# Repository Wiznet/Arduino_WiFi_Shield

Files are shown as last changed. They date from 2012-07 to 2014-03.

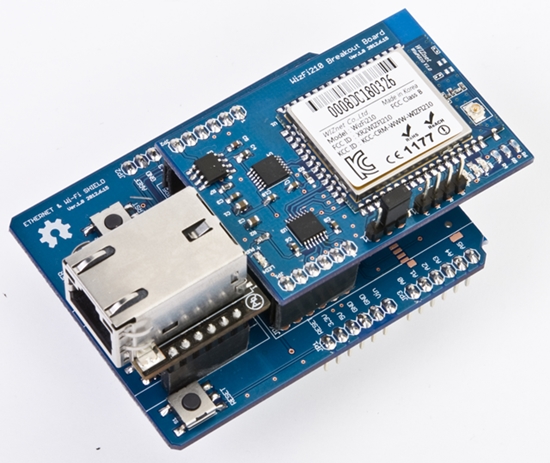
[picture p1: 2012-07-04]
WizFi_Shield.jpg

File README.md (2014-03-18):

# Wi-Fi Shield for Arduino using [WizFi210](http://www.wiznet.co.kr/WizFi210) from [Wiznet](http://www.wiznet.co.kr/)

WizFi Shield

## Hardware
These are PCB files for the WizFi Shield for Arduino. The files were created in the free & low cost EagleCad software available form [here](http://www.cadsoftusa.com/download-eagle/?language=en).

## Software
These are driver code of WizFi shield and test code.
For Arduino library source code, refer to https://github.com/Wiznet/WizFiShield

## Documents
Manual for WizFi shield

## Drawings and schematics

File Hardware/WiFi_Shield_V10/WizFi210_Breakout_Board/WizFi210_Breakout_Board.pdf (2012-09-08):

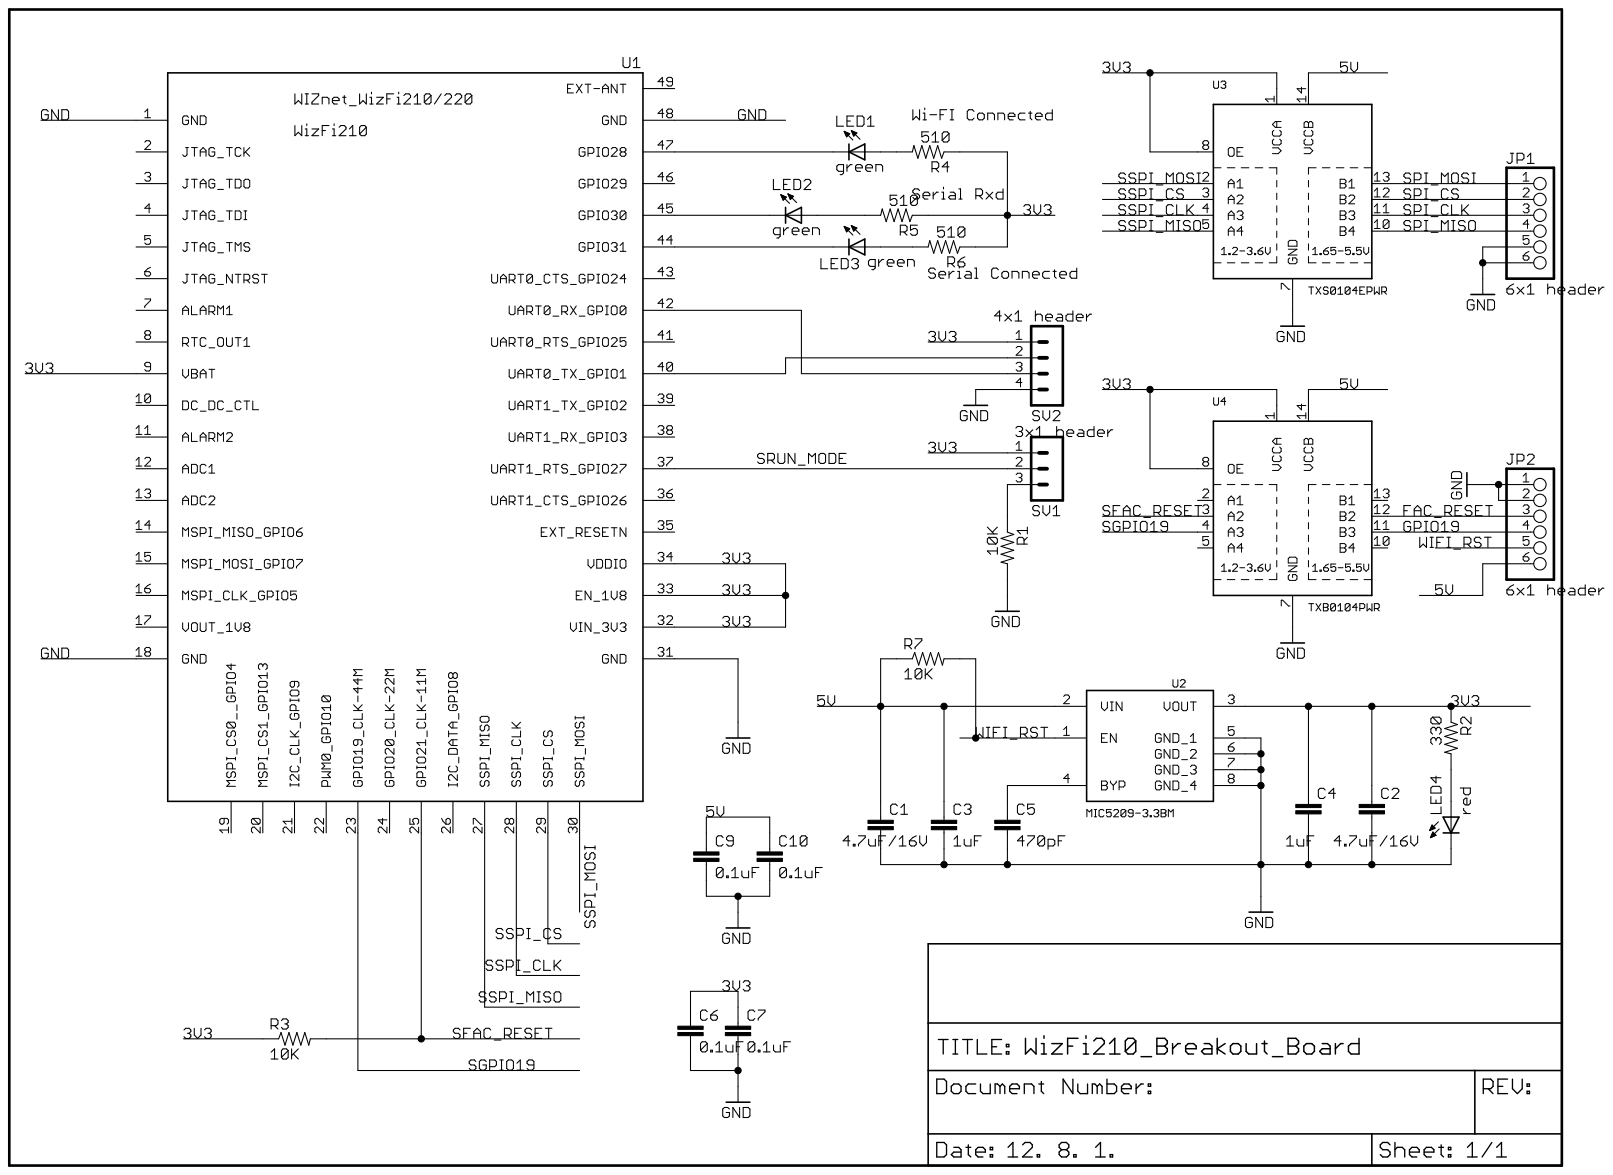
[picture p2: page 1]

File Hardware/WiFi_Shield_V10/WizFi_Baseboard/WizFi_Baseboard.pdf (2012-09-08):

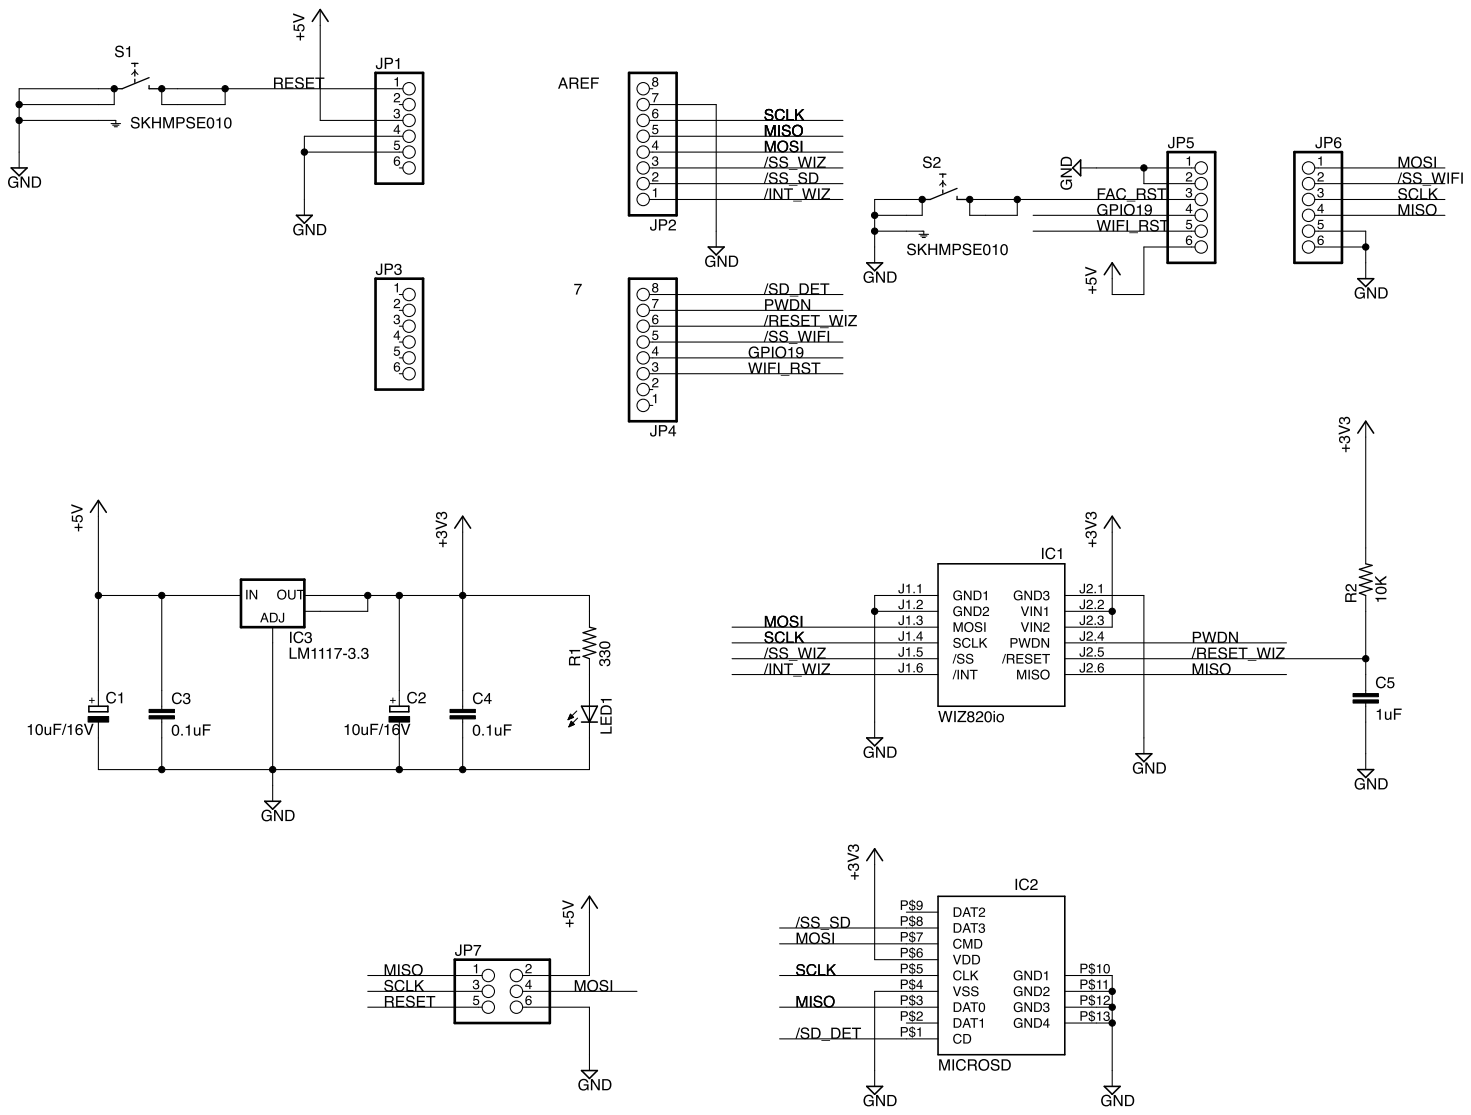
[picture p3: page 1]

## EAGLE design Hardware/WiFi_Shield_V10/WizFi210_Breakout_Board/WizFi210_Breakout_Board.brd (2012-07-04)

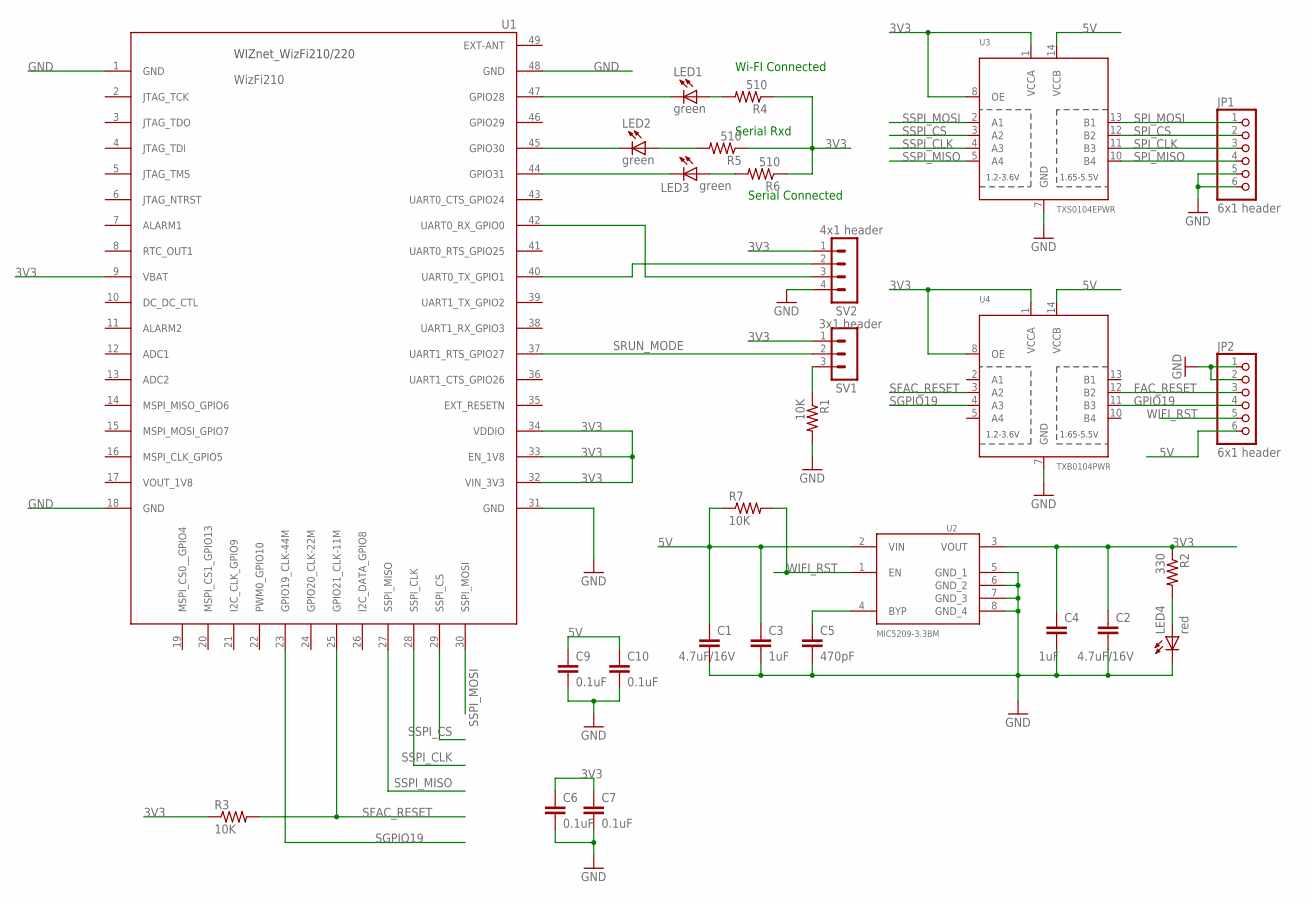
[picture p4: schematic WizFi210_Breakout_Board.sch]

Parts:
C1: 4.7uF/16V; C0805
C2: 4.7uF/16V; C0603
C3: 1uF; C0603
C4: 1uF; C0805
C5: 470pF; C0603
C6, C7, C9, C10: 0.1uF; C0603
JP1, JP2: 6x1 header; 1X06
LED1, LED2, LED3: green; CHIP-LED0805
LED4: red; CHIP-LED0805
R1, R3, R7: 10K; 0603-RES
R2: 330; 0603-RES
R4, R5, R6: 510; 0603-RES
SV1: 3x1 header; MA03-1
SV2: 4x1 header; MA04-1
U1: WizFi210; WIZFI210/220
U2: MIC5209-3.3BM; SO08
U3: TXS0104EPWR; TSSOP14
U4: TXB0104PWR; TSSOP14

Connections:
3V3: C2.1, C4.1, C6.1, C7.1, R2.1, R3.1, R4.1, R5.1, R6.1, SV1.1, SV2.1, U1.9 (VBAT), U1.32 (VIN_3V3), U1.33 (EN_1V8), U1.34 (VDDIO), U2.3 (VOUT), U3.1 (VCCA), U3.8 (OE), U4.1 (VCCA), U4.8 (OE)
5V: C1.1, C3.1, C9.1, C10.1, JP2.6, R7.1, U2.2 (VIN), U3.14 (VCCB), U4.14 (VCCB)
FAC_RESET: JP2.3, U4.12 (B2)
GND: C1.2, C2.2, C3.2, C4.2, C5.2, C6.2, C7.2, C9.2, C10.2, JP1.5, JP1.6, JP2.1, JP2.2, LED4.C, R1.2, SV2.4, U1.1 (GND), U1.18 (GND), U1.31 (GND), U1.48 (GND), U2.5 (GND_1), U2.6 (GND_2), U2.7 (GND_3), U2.8 (GND_4), U3.7 (GND), U4.7 (GND)
GPIO19: JP2.4, U4.11 (B3)
GPIO28: LED1.C, U1.47 (GPIO28)
GPIO30: LED2.C, U1.45 (GPIO30)
GPIO31: LED3.C, U1.44 (GPIO31)
unnamed: R1.1, SV1.3
unnamed: LED4.A, R2.2
unnamed: C5.1, U2.4 (BYP)
unnamed: LED1.A, R4.2
unnamed: LED2.A, R5.2
unnamed: LED3.A, R6.2
SFAC_RESET: R3.2, U1.25 (GPIO21_CLK-11M), U4.3 (A2)
SGPIO19: U1.23 (GPIO19_CLK-44M), U4.4 (A3)
SPI_CLK: JP1.3, U3.11 (B3)
SPI_CS: JP1.2, U3.12 (B2)
SPI_MISO: JP1.4, U3.10 (B4)
SPI_MOSI: JP1.1, U3.13 (B1)
SRUN_MODE: SV1.2, U1.37 (UART1_RTS_GPIO27)
SSPI_CLK: U1.28 (SSPI_CLK), U3.4 (A3)
SSPI_CS: U1.29 (SSPI_CS), U3.3 (A2)
SSPI_MISO: U1.27 (SSPI_MISO), U3.5 (A4)
SSPI_MOSI: U1.30 (SSPI_MOSI), U3.2 (A1)
UART0_RX: SV2.3, U1.42 (UART0_RX_GPIO0)
UART0_TX: SV2.2, U1.40 (UART0_TX_GPIO1)
WIFI_RST: JP2.5, R7.2, U2.1 (EN)

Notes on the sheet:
Wi-FI Connected
Serial Rxd
Serial Connected

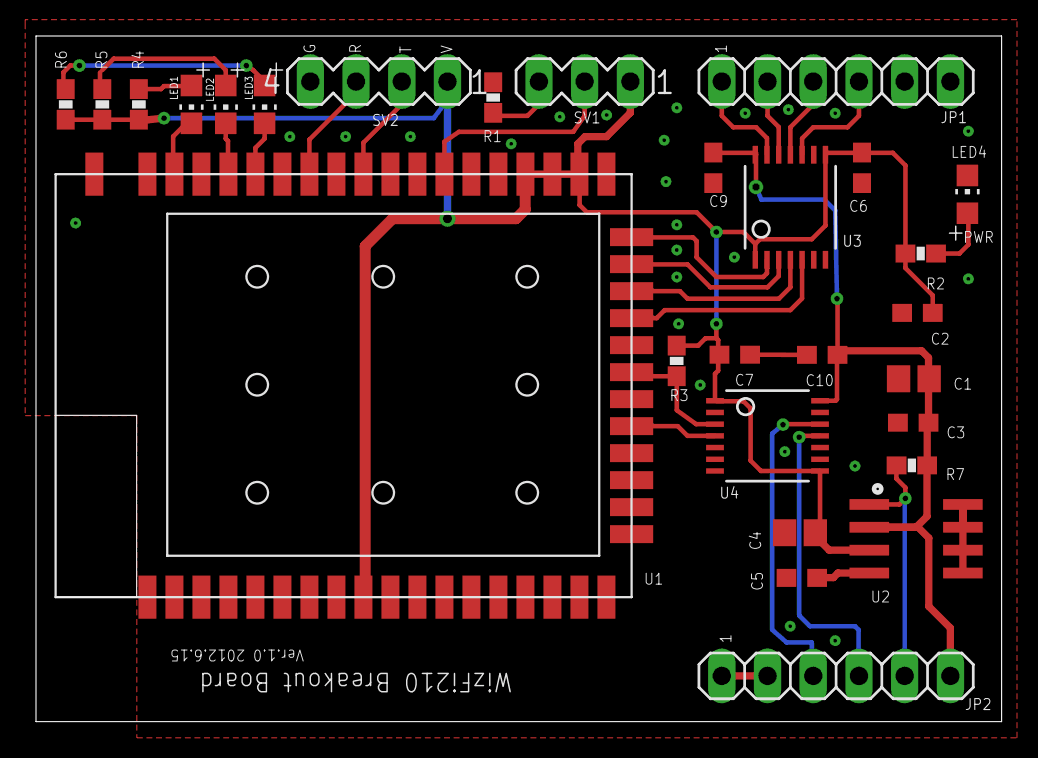
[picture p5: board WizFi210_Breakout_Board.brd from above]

Board: 2 copper layers, 53.6 x 38.1 mm, 29 parts (1 on the bottom side), 28 nets.

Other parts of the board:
U$1: WIZNET_LOGO_PAC

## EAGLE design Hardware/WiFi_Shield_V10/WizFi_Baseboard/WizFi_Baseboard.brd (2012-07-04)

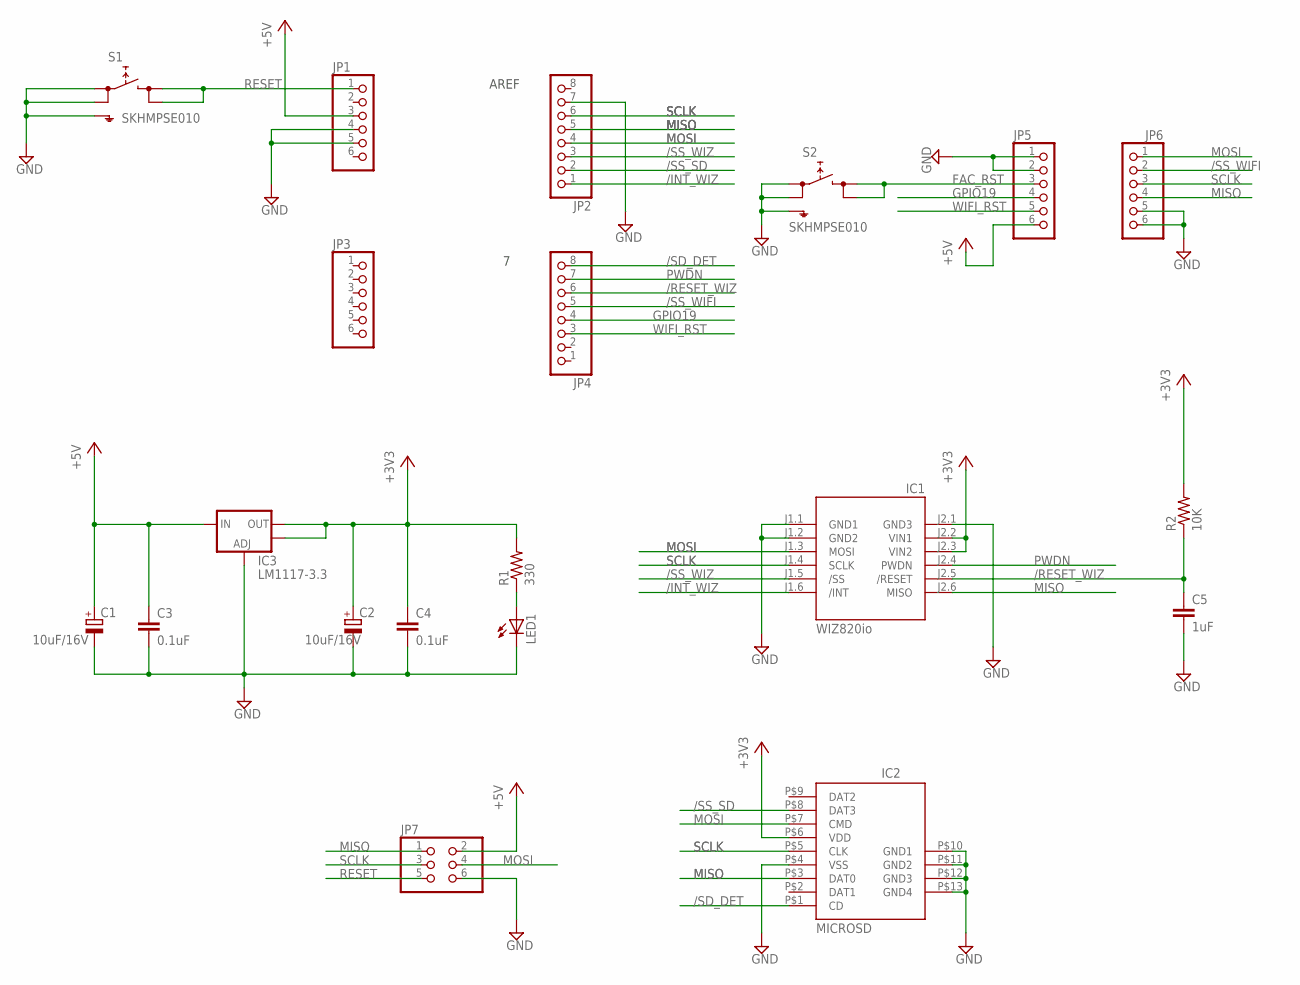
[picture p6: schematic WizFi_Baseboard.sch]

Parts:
C1, C2: 10uF/16V; CT3216
C3, C4: 0.1uF; C0805
C5: 1uF; C0805
IC1: WIZ820io; WIZ820IO
IC2: MICROSD; MSDPAC
IC3: LM1117-3.3; SOT223
JP1, JP3, JP5, JP6: PINHD-1X6; 1X06
JP2, JP4: PINHD-1X8; 1X08
JP7: PINHD-2X3; 2X03
LED1: LEDCHIP-LED0805; CHIP-LED0805
R1: 330; R0805
R2: 10K; R0805
S1, S2: SKHMPSE010; SKHMPXE010

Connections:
+3V3: C2.+, C4.1, IC1.J2.2 (VIN1), IC1.J2.3 (VIN2), IC2.P$6 (VDD), IC3.2 (OUT), IC3.4 (OUT), R1.2, R2.2
+5V: C1.+, C3.1, IC3.3 (IN), JP1.3, JP5.6, JP7.2
/INT_WIZ: IC1.J1.6 (/INT), JP2.1
/RESET_WIZ: C5.1, IC1.J2.5 (/RESET), JP4.6, R2.1
/SD_DET: IC2.P$1 (CD), JP4.8
/SS_SD: IC2.P$8 (DAT3), JP2.2
/SS_WIFI: JP4.5, JP6.2
/SS_WIZ: IC1.J1.5 (/SS), JP2.3
FAC_RST: JP5.3, S2.3 (2.1), S2.4 (2.2)
GND: C1.-, C2.-, C3.2, C4.2, C5.2, IC1.J1.1 (GND1), IC1.J1.2 (GND2), IC1.J2.1 (GND3), IC2.P$4 (VSS), IC2.P$10 (GND1), IC2.P$11 (GND2), IC2.P$12 (GND3), IC2.P$13 (GND4), IC3.1 (ADJ), JP1.4, JP1.5, JP2.7, JP5.1, JP5.2, JP6.5, JP6.6, JP7.6, LED1.C, S1.1 (1.1), S1.2 (1.2), S1.5 (SH), S2.1 (1.1), S2.2 (1.2), S2.5 (SH)
GPIO19: JP4.4, JP5.4
MISO: IC1.J2.6 (MISO), IC2.P$3 (DAT0), JP2.5, JP6.4, JP7.1
MOSI: IC1.J1.3 (MOSI), IC2.P$7 (CMD), JP2.4, JP6.1, JP7.4
unnamed: LED1.A, R1.1
PWDN: IC1.J2.4 (PWDN), JP4.7
RESET: JP1.1, JP7.5, S1.3 (2.1), S1.4 (2.2)
SCLK: IC1.J1.4 (SCLK), IC2.P$5 (CLK), JP2.6, JP6.3, JP7.3
WIFI_RST: JP4.3, JP5.5

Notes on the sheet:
AREF
SCLK
MISO
MOSI

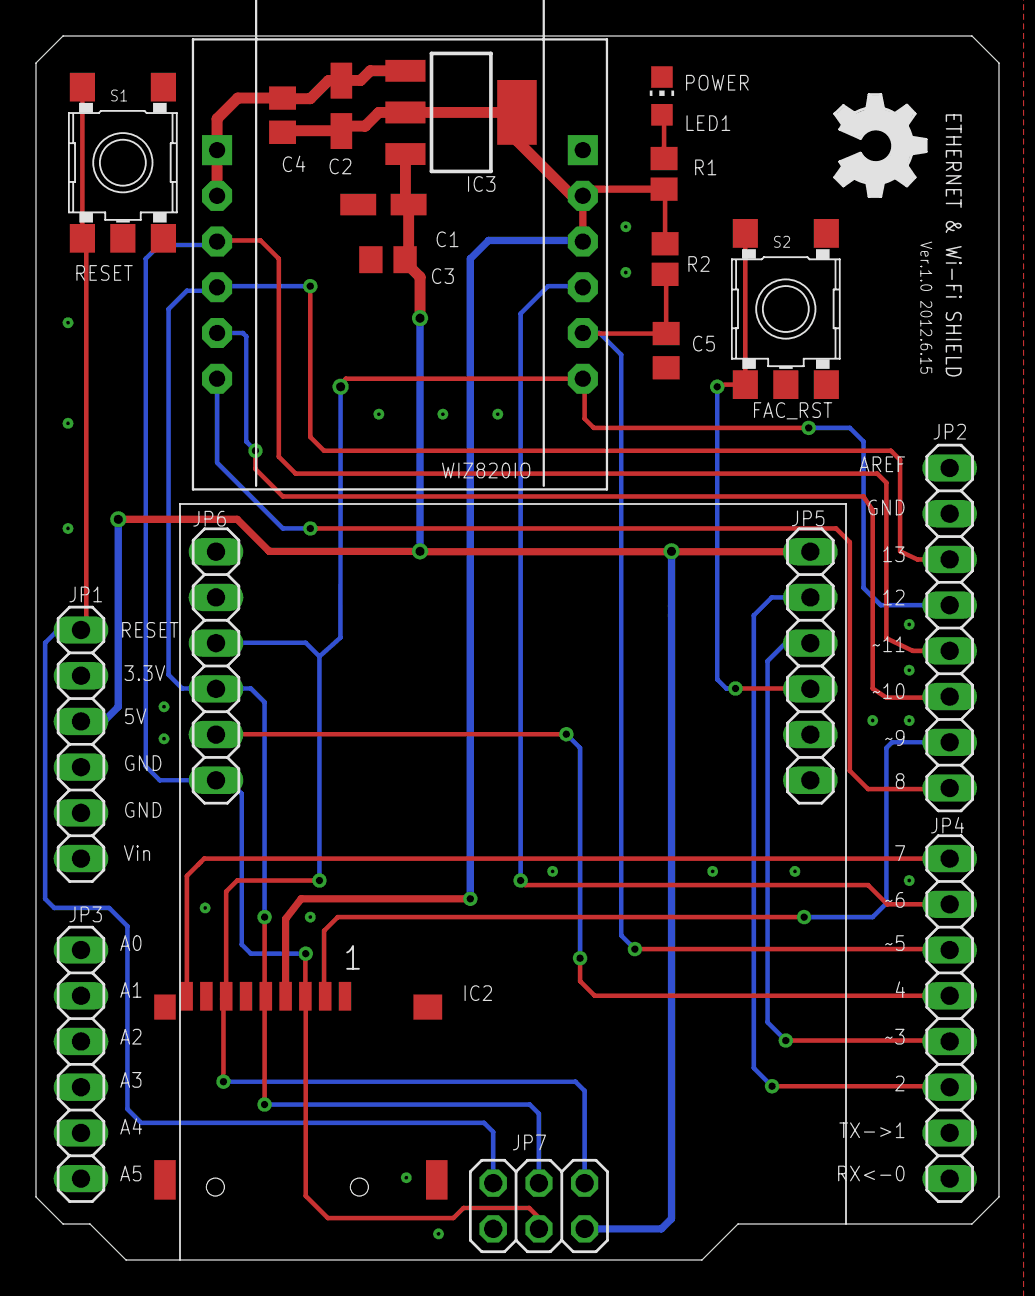
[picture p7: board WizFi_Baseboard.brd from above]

Board: 2 copper layers, 53.5 x 68.0 mm, 22 parts (1 on the bottom side), 18 nets.

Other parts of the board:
U$1: OSHW_FILLX200_NOTEXT
U$2: WIZNET_LOGO_PAC

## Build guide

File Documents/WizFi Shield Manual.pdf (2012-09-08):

# WizFi

# Shield Manual

Introduction
WizFi

shield uses
Wiz820io, WizFi210 module and supports the Ethernet and Wi-Fi connectivity simultaneously.

### 1. Hardware

a) Ethernet

-‐.

Wiz820io is

connected

with

SPI

signals.

-‐.

Other signals
- /SS_WIZ

(Input):

SPI

slave

chip

select

signal
- /RESET_WIZ (Input):

H/W

reset signal
- PWDN

(Input):

Set

power

down

mode
- /INT_WIZ

(Output):

Interrupt

signal

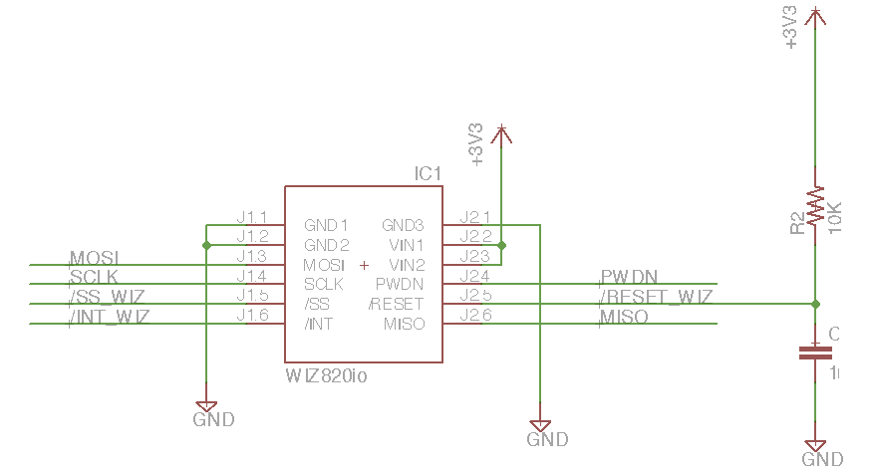
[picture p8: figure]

b) Wi-‐Fi

-‐.

WizFi210 module

is

connected

with

SPI

signals

-‐.

Other

signals
- /SS_WIFI(Input):

SPI

slave

chip

select

signal
- FAC_RST

(Input):

Factory

reset
- GPIO19

(Output):

If

this

signal

is

high,

indicate

the

data

in

the

receive

buffer
in

the

WizFi210
- WIFI_RST

(Input):

Reset

signal

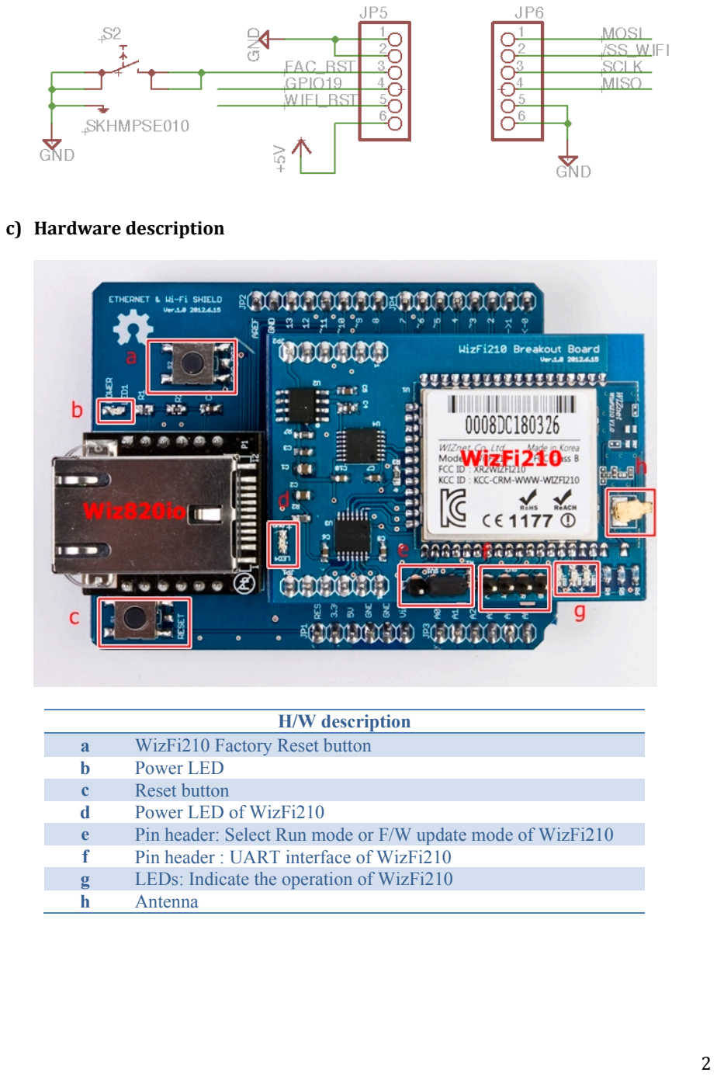
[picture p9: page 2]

c) Hardware

description

H/W description
a | WizFi210 Factory Reset button
b | Power LED
c | Reset button
d | Power LED of WizFi210
e | Pin header: Select Run mode or F/W update mode of WizFi210
f | Pin header : UART interface of WizFi210
g | LEDs: Indicate the operation of WizFi210
h | Antenna

### 2. How

to

test?
a) Test

environments

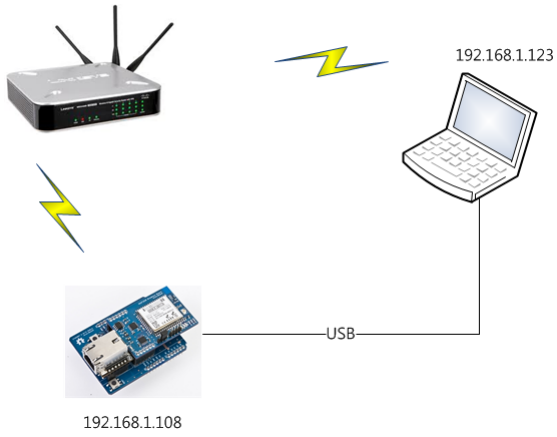
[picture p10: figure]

-‐.

Download

the

source

code

“WizFi_Shield_Test.ino” from https://github.com/Wiznet/Arduino_WiFi_Shield and

open it

with

Arduino

IDE.

-‐.

You

have

to

change

the

SSID

&

Wi-‐FI

password

according

to

your

Wi-‐Fi

router.
#define

SSID

"WIZnetCisco"

//

SSID

of

your

AP
#define

WPA_PASS

"0557564860"

//

WPA

Password

-‐.

WizFi

Shield

gets the

IP

address

using

DHCP

and

works

as

TCP

server.

-‐.

Laptop

connects

to

it.

After

the

connection

is

established,

the

data

between

the
laptop

and

WizFi

shield

is

transparent.

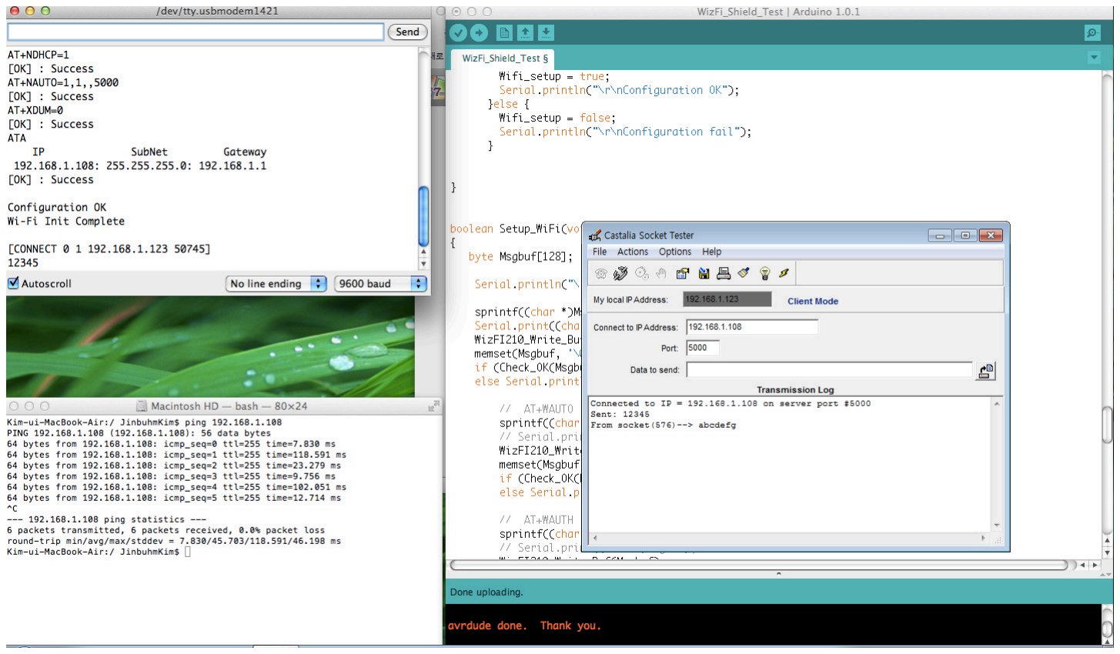
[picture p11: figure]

3. Reference.
- Arduino
source code & schematics can be download from Wiznet Github https://github.com/Wiznet/Arduino_WiFi_Shield
- WizFi210 datasheet
- Wiz820io datasheet

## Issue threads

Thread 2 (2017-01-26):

Not working with Due and Arduino pro mini

sriranjanr, 2017-01-26:
Hello,

I tried to get this code working with a Wizfi210 (not the shield) with Arduino pro mini 8mhz. I also tried to get it working with Arduino Due (after modifying the SPI code).In both cases this code is not working.I get the serial prints but AT commands are not working. I am able to get "Send sync Data, OK" but not after this. It fails at AT command. Please tell me what I should do for both Due and pro mini.

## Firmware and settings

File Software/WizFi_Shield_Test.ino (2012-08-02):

/*
 WizFi210 Arduino test code
 
 Circuit:
 WizFi210 connected to Arduino via SPI
 
 RST: pin 2  // Output
 DRDY: pin 3  // Input
 CSB: pin 4  // output

 MOSI: pin 11  // output
 MISO: pin 12
 SCK: pin 13  // out
 
 Created 15 May 2012
 by Jinbuhm Kim  (jbkim@wiznet, Jinbuhm.Kim@gmail.com)

 */

// WizFi210 communicates using SPI, so include the SPI library:
#include <stdio.h>
#include <stdlib.h>
#include <string.h>
#include <SPI.h>

#define DHCP_ENABLE

const byte SPI_ESC_CHAR  = 0xFB;       /* Start transmission indication */
const byte SPI_IDLE_CHAR = 0xF5;       /* synchronous IDLE */
const byte SPI_XOFF_CHAR = 0xFA;       /* Stop transmission indication */
const byte SPI_XON_CHAR = 0xFD;        /* Start transmission indication */      
const byte SPI_INVALID_CHAR_ALL_ONE = 0xFF;    /* Invalid character possibly recieved during reboot */
const byte SPI_INVALID_CHAR_ALL_ZERO = 0x00;    /* Invalid character possibly recieved during reboot */
const byte SPI_LINK_READY = 0xF3;     /* SPI link ready */

#define SSID 		"WIZnetCisco"        // SSID of your AP
#define WPA_PASS 	"0557564860"         // WPA Password

#define Infrastructure	0
#define Ad_hoc		1

#define Client_Mode	0
#define Server_Mode	1

#define Protocol_UDP	0
#define Protocol_TCP	1

// for static IP address
unsigned char IP[4] 		= {192, 168, 88, 123};
unsigned char  Sub[4] 	        = {255, 255, 255, 0};
unsigned char  Gw[4] 		= {192, 168, 88, 1};
unsigned char  SIP[4] 	        = {192, 168, 88, 228};
unsigned int ListenPort = 5000;
unsigned int ServerPort = 5000;


// pins used for the connection with the WizFi210
const int rstPin = 2;
const int dataReadyPin = 3;
const int chipSelectPin = 4;

boolean Wifi_setup = false;

void setup() {
  Serial.begin(9600);
  Serial.println("\r\nSerial Init");
  
  // initalize the  data ready and chip select pins:
  pinMode(dataReadyPin, INPUT);
  pinMode(chipSelectPin, OUTPUT);
  pinMode(rstPin, OUTPUT);
  
  // start the SPI library:
    SPI.setDataMode(SPI_MODE0);
    SPI.setBitOrder(MSBFIRST);
    SPI.setClockDivider(SPI_CLOCK_DIV128); //
    SPI.begin();

  digitalWrite(chipSelectPin, HIGH);
  digitalWrite(rstPin, HIGH);

  Serial.println("Wi-Fi Reset");
  digitalWrite(rstPin, LOW);
  delay(500);
  
  digitalWrite(rstPin, HIGH);
  delay(6000); // 

  Serial.println("Wi-Fi Init");
  Init();
  Serial.println("Wi-Fi Init Complete");
}

void loop() {
  byte tmp;
  
  if (Wifi_setup == true) {
        
        // if there is data from Wi-Fi side. 
	tmp = WizFI210_Read_Byte();
	if ((tmp != SPI_IDLE_CHAR) &&  (tmp != SPI_INVALID_CHAR_ALL_ZERO) && (tmp != SPI_INVALID_CHAR_ALL_ONE)){
             Serial.print(char(tmp));
	}
        
        // if the connection is established, incoming serial data sent to the peer.
        if (Serial.available() > 0) {
          WizFI210_Write_Byte(Serial.read());
        }

    
  }
}

byte WizFI210_Read_Byte() {
    byte result;
    
    digitalWrite(chipSelectPin, LOW);
    result = SPI.transfer(0);
    digitalWrite(chipSelectPin, HIGH);
    return(result);
}

unsigned int WizFI210_Read_Buf(byte * buf)
{
	int idx = 0;
	byte tmp;
	byte chk = 0;
	
	while(digitalRead(dataReadyPin) == HIGH) {

		tmp = WizFI210_Read_Byte();

		if ((tmp != SPI_IDLE_CHAR) &&  (tmp != SPI_INVALID_CHAR_ALL_ZERO) && (tmp != SPI_INVALID_CHAR_ALL_ONE))	{
			if (tmp == SPI_ESC_CHAR) {
				chk = 1;
			}else {
				if (chk == 1) {
					chk = 0;
					tmp = tmp ^ 0x20;
				}
				buf[idx++] = tmp;
			}
		}
	}

	return(idx);
}


byte SpiByteStuff(byte *thisValue)
 {
 if( (SPI_ESC_CHAR	== *thisValue) ||
	 (SPI_XON_CHAR	== *thisValue) ||
	 (SPI_XOFF_CHAR == *thisValue) ||
	 (SPI_IDLE_CHAR == *thisValue) ||
	 (SPI_INVALID_CHAR_ALL_ONE == *thisValue) ||
	 (SPI_INVALID_CHAR_ALL_ZERO == *thisValue)||
	 (SPI_LINK_READY == *thisValue))
 	{   // Byte stuffing is required
		 *thisValue = *thisValue ^ 0x20;
		 return 0x01;
	 }
	 else
	 {
		 return 0x00;
	 }

 } 

void WizFI210_Write_Byte(byte thisValue) 
{
  if (SpiByteStuff(&thisValue)) {
    digitalWrite(chipSelectPin, LOW);
    // Byte stuffing is required.
    SPI.transfer(SPI_ESC_CHAR);
    digitalWrite(chipSelectPin, HIGH);
    }

    digitalWrite(chipSelectPin, LOW);
    SPI.transfer(thisValue);
    digitalWrite(chipSelectPin, HIGH);
}

void WizFI210_Write_Buf(byte *s)
{
  while (*s != '\0')
  {
    if (SpiByteStuff(s)) {
      digitalWrite(chipSelectPin, LOW);
      // Byte stuffing is required.
      SPI.transfer(SPI_ESC_CHAR);
      digitalWrite(chipSelectPin, HIGH);
    }

    digitalWrite(chipSelectPin, LOW);
    SPI.transfer(*s);
    digitalWrite(chipSelectPin, HIGH);
    s ++;
    }
    delay(10);
}

byte Check_OK(byte * buf, unsigned int TimeOut)
{
	unsigned int idx = 0;
	unsigned int t=0;
	byte tmp;
	char * ret = NULL;
        
	while(1) {

		tmp = WizFI210_Read_Byte();
		if ((tmp != SPI_IDLE_CHAR) &&  (tmp != SPI_INVALID_CHAR_ALL_ZERO) && (tmp != SPI_INVALID_CHAR_ALL_ONE)){
                    
			buf[idx++] = tmp;
                        //if (idx > sizeof(buf)) idx = 0;
                        Serial.print(char(tmp));

			if (tmp == ']') break;
		}

		if (t++ > TimeOut) {
                  //  Serial.println("Time out");
                    break;
                }
		delay(10);
	}

    // flush
    while(digitalRead(dataReadyPin) == HIGH) {
  	WizFI210_Read_Byte();
        delay(10);
    }

	ret = strstr((char *)buf, "[OK]");
	if (ret != NULL) {
          return 1;
        } else {
          return 0;
        }
}

byte IsCommandMode()
{
    byte msg[]="AT\r\n";

    WizFI210_Write_Buf(msg);
    memset(msg, '\0', sizeof(msg));
    return(Check_OK(msg, 2000));
}

void Init(void)
{
   byte Msgbuf[68];
   byte key;

 Serial.println("Send Sync data");
 WizFI210_Write_Byte(SPI_IDLE_CHAR);
 delay(1000);

  while(1) {
	key = WizFI210_Read_Byte();
	if ((key != SPI_IDLE_CHAR) &&  (key != SPI_INVALID_CHAR_ALL_ZERO) && (key != SPI_INVALID_CHAR_ALL_ONE)) {
                // debug
		//Serial.print(char(key));
	}
       if (digitalRead(dataReadyPin) == LOW) break;
        delay(10);
  }
  
 Serial.println("Ok");

        // Send AT
        Serial.print("\r\nSend AT");
	sprintf((char *)Msgbuf, "AT\r");
	WizFI210_Write_Buf(Msgbuf);
	memset(Msgbuf, '\0', sizeof(Msgbuf));
        
	if (Check_OK(Msgbuf, 2000))  Serial.print(" : Success");
	else {
                Serial.println("\r\nSend 2nd AT");
		sprintf((char *)Msgbuf, "AT\r");
		WizFI210_Write_Buf(Msgbuf);
		memset(Msgbuf, '\0', sizeof(Msgbuf));
		if (Check_OK(Msgbuf, 2000))  Serial.println(" : Success");
		else Serial.println(" : Error");
	}
       
      if (Setup_WiFi() == true) {
        Wifi_setup = true;
        Serial.println("\r\nConfiguration OK");    
      }else { 
        Wifi_setup = false;
        Serial.println("\r\nConfiguration fail");    
      }

 
}


boolean Setup_WiFi(void)
{
   byte Msgbuf[128];

    Serial.println("\r\nTest Command");
    
    sprintf((char *)Msgbuf, "AT+WD\r");
    Serial.print((char *)Msgbuf);
    WizFI210_Write_Buf(Msgbuf);
    memset(Msgbuf, '\0', sizeof(Msgbuf));
    if (Check_OK(Msgbuf, 10000)) Serial.println(" : Success");
    else Serial.println(" : Error");
    
	//  AT+WAUTO
	sprintf((char *)Msgbuf, "AT+WAUTO=0,%s\r\n", SSID);
        // Serial.print((char *)Msgbuf);
	WizFI210_Write_Buf(Msgbuf);
	memset(Msgbuf, '\0', sizeof(Msgbuf));
	if (Check_OK(Msgbuf, 1000)) Serial.println(" : Success");
	else Serial.println(" : Error");

	//  AT+WAUTH
	sprintf((char *)Msgbuf, "AT+WAUTH=%d\r\n",0);
        // Serial.print((char *)Msgbuf);
	WizFI210_Write_Buf(Msgbuf);
	memset(Msgbuf, '\0', sizeof(Msgbuf));
	if (Check_OK(Msgbuf, 1000)) Serial.println(" : Success");
	else Serial.println(" : Error");

	//  AT+WWPA
	sprintf((char *)Msgbuf, "AT+WWPA=%s\r\n",WPA_PASS);
        // Serial.print((char *)Msgbuf);
	WizFI210_Write_Buf(Msgbuf);
	memset(Msgbuf, '\0', sizeof(Msgbuf));
	if (Check_OK(Msgbuf, 1000)) Serial.println(" : Success");
	else Serial.println(" : Error");

#ifdef DHCP_ENABLE
	//  AT+NDHCP
	sprintf((char *)Msgbuf, "AT+NDHCP=%d\r\n",1);
        // Serial.print((char *)Msgbuf);
	WizFI210_Write_Buf(Msgbuf);
	memset(Msgbuf, '\0', sizeof(Msgbuf));
	if (Check_OK(Msgbuf, 1000)) Serial.println(" : Success");
	else Serial.println(" : Error");
#else
	//  AT+NDHCP
	sprintf((char *)Msgbuf, "AT+NDHCP=%d\r\n",0);
        // Serial.print((char *)Msgbuf);
	WizFI210_Write_Buf(Msgbuf);
	memset(Msgbuf, '\0', sizeof(Msgbuf));
	if (Check_OK(Msgbuf, 1000)) Serial.println(" : Success");
	else Serial.println(" : Error");

	//  AT+NSET
	sprintf((char *)Msgbuf, "AT+NSET=%d.%d.%d.%d,%d.%d.%d.%d,%d.%d.%d.%d\r\n", 
					IP[0],IP[1],IP[2],IP[3],Sub[0],Sub[1],Sub[2],Sub[3],Gw[0],Gw[1],Gw[2],Gw[3]);
        // Serial.print((char *)Msgbuf);
	WizFI210_Write_Buf(Msgbuf);
	memset(Msgbuf, '\0', sizeof(Msgbuf));
	if (Check_OK(Msgbuf, 1000)) Serial.println(" : Success");
	else Serial.println(" : Error");
#endif

	//  AT+NAUTO
	sprintf((char *)Msgbuf, "AT+NAUTO=%d,%d,,%d\r\n",Server_Mode, Protocol_TCP, ListenPort);
        // Serial.print((char *)Msgbuf);
	WizFI210_Write_Buf(Msgbuf);
	memset(Msgbuf, '\0', sizeof(Msgbuf));
	if (Check_OK(Msgbuf, 1000)) Serial.println(" : Success");
	else Serial.println(" : Error");

	//  AT+XDUM
	sprintf((char *)Msgbuf, "AT+XDUM=%d\r\n", 0); //  1: Uart message is disable, 0: enable
        // Serial.print((char *)Msgbuf);
	WizFI210_Write_Buf(Msgbuf);
	memset(Msgbuf, '\0', sizeof(Msgbuf));
	if (Check_OK(Msgbuf, 1000)) Serial.println(" : Success");
	else Serial.println(" : Error");

/*
        // MAC address writing
	sprintf((char *)Msgbuf, "AT+NMAC=00:08:DC:18:76:57\r\n"); 
        Serial.print((char *)Msgbuf);
	WizFI210_Write_Buf(Msgbuf);
	memset(Msgbuf, '\0', sizeof(Msgbuf));
	if (Check_OK(Msgbuf, 1000)) Serial.println(" : Success");
	else Serial.println(" : Error");
*/	
	//  ATA
	sprintf((char *)Msgbuf, "ATA\r\n");
        //Serial.print((char *)Msgbuf);
	WizFI210_Write_Buf(Msgbuf);
	memset(Msgbuf, '\0', sizeof(Msgbuf));
	if (Check_OK(Msgbuf, 20000)) {
          Serial.println(" : Success");
          return true;
        }
	else {
          Serial.println(" : Error");
          return false;
        }

}

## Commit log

2012-07-04 WizFi Shield Hardware Files
    [WizFi210_Breakout_Board.brd, WizFi210_Breakout_Board.sch, WizFi_Baseboard.brd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]
2012-07-04 Board image upload
2012-09-08 PDF schematics update
2013-02-01 Change Readme
    Adding comment for Arduino Lib.

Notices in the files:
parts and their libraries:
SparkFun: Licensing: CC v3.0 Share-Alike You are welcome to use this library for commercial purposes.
